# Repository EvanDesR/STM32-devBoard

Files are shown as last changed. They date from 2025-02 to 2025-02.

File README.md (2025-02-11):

# STM32-devBoard

At one point I was considering electrical or computer hardware engineering as a degree, but I decided to just keep it a hobby. This is most recent/best hardware project.

## Board design
Screenshot from 2025-02-10 18-38-12

## Connection plotter
Screenshot from 2025-02-10 18-38-58

## Did you know you can put corporate logos on PCBs, and JLCPCB wont complain?! 
Screenshot from 2025-02-10 18-39-17
Screenshot from 2025-02-10 18-52-23

## A closer look at the board layout. Designed with minimizing noise in mind.
Screenshot from 2025-02-10 18-52-32

## PCB render from development


## After finishing the .bom (bill of materials) file for JLCPCB, I submitted the design for approval, and manufactuering 



## About two weeks later...





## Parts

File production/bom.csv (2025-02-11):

Designator | Footprint | Quantity | Value | LCSC Part #
C1, C2 | 0805 | 2 | 22u | C45783
C10, C9 | 0402 | 2 | 1u | C52923
C11, C4, C5, C6, C7 | 0402 | 5 | 100n | C2981728
C12, C13 | 0402 | 2 | 8p | C342939
C3 | 0603 | 1 | 10u | C19702
C8 | 0402 | 1 | 10n | C15195
D1 | 0603 | 1 | RED | C2286
FB1 | 0805 | 1 | 120R | C160964
H1, H2 | MountingHole_2.2mm_M2 | 2 | MountingHole
J1, J3, J5 | PinHeader_1x04_P2.54mm_Vertical | 3 | Conn_01x04_Male | C2691448
J2 | MICRO-USB-SMD_5P-P0.65-H-F_U254-051T-4BH81-S2S | 1 | U254-051T-4BH81-S2S | C381144
J4 | PinHeader_1x04_P2.54mm_Vertical | 1 | Conn_01x04_Male | C2691448
R1, R3, R4, R5 | 0402 | 4 | 1k5 | C319978
R2 | 0402 | 1 | 10k | C269701
SW1 | SW_SPDT_PCM12 | 1 | SW_SPDT | C5149818
U1 | SOT-223-3_TabPin2 | 1 | AMS1117-3.3 | C6186
U2 | LQFP-48_7x7mm_P0.5mm | 1 | STM32F103C8T6 | C8734
Y1 | Crystal_SMD_3225-4Pin_3.2x2.5mm | 1 | 16MHz | C129740

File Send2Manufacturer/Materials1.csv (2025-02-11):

Source: | /home/wockyslush/kicads/ProjOne/ProjOne.kicad_sch
Date: | Tue 26 Mar 2024 10:59:46 PM
Tool: | Eeschema 6.0.2+dfsg-1
Generator: | /usr/share/kicad/plugins/bom_csv_grouped_by_value_with_fp.py
Component Count: | 31
Ref | Qnty | Value | Cmp name | Footprint | Description | Vendor
C1, C2, | 2 | 22u | C | Capacitor_SMD:C_0805_2012Metric | Unpolarized capacitor
C3, | 1 | 10u | C | Capacitor_SMD:C_0603_1608Metric_Pad1.08x0.95mm_HandSolder | Unpolarized capacitor
C4, C5, C6, C7, C11, | 5 | 100n | C | Capacitor_SMD:C_0402_1005Metric | Unpolarized capacitor
C8, | 1 | 10n | C | Capacitor_SMD:C_0402_1005Metric | Unpolarized capacitor
C9, C10, | 2 | 1u | C | Capacitor_SMD:C_0402_1005Metric | Unpolarized capacitor
C12, C13, | 2 | 10p | C | Capacitor_SMD:C_0402_1005Metric | Unpolarized capacitor
D1, | 1 | RED | LED | LED_SMD:LED_0603_1608Metric | Light emitting diode
FB1, | 1 | 120R | FerriteBead | Inductor_SMD:L_0201_0603Metric | Ferrite bead
J1, J3, J5, | 3 | Conn_01x04_Male | Conn_01x04_Male | Connector_PinHeader_2.54mm:PinHeader_1x04_P2.54mm_Vertical | Generic connector, single row, 01x04, script generated (kicad-library-utils/schlib/autogen/connector/)
J2, | 1 | USB_B_Micro | USB_B_Micro | Connector_USB:USB_Micro-B_Wuerth_629105150521 | USB Micro Type B connector
J4, | 1 | Conn_01x04_Male | Conn_01x04_Male | Connector_PinHeader_2.54mm:PinHeader_1x04_P2.54mm_Vertical | Generic connector, single row, 01x04, script generated (kicad-library-utils/schlib/autogen/connector/)
R1, R3, R4, R5, | 4 | 1k5 | R | Resistor_SMD:R_0402_1005Metric | Resistor
R2, | 1 | 10k | R | Resistor_SMD:R_0402_1005Metric | Resistor
SW1, | 1 | SW_SPDT | SW_SPDT | Button_Switch_THT:SW_E-Switch_EG1224_SPDT_Angled | Switch, single pole double throw
U1, | 1 | AMS1117-3.3 | AMS1117-3.3 | Package_TO_SOT_SMD:SOT-223-3_TabPin2 | 1A Low Dropout regulator, positive, 3.3V fixed output, SOT-223
U2, | 1 | STM32F103C8T6 | STM32F103C8Tx | Package_QFP:LQFP-48_7x7mm_P0.5mm | ARM Cortex-M3 MCU, 64KB flash, 20KB RAM, 72MHz, 2-3.6V, 37 GPIO, LQFP-48
Y1, | 1 | 16MHz | Crystal_GND24 | Crystal:Crystal_SMD_3225-4Pin_3.2x2.5mm | Four pin crystal, GND on pins 2 and 4

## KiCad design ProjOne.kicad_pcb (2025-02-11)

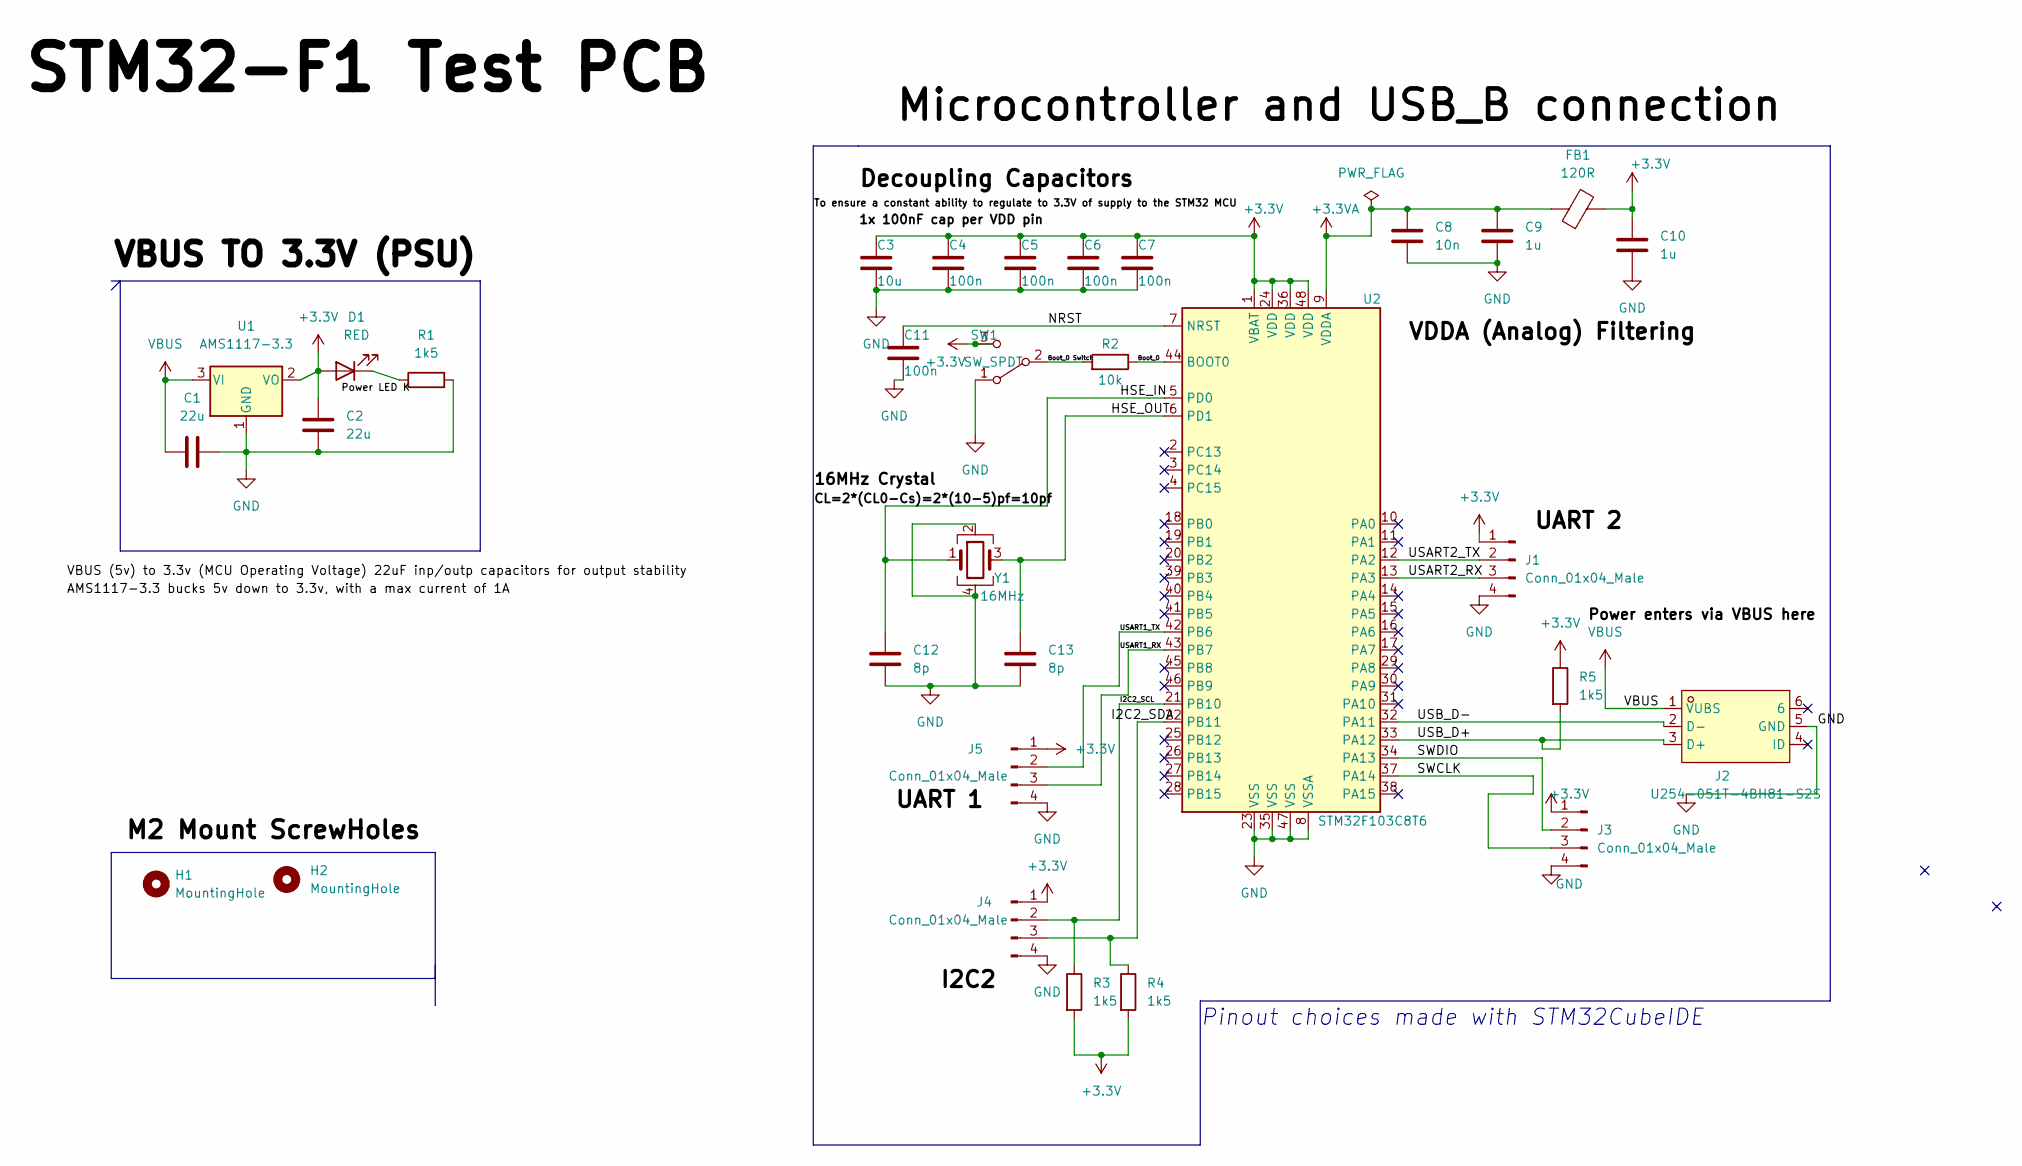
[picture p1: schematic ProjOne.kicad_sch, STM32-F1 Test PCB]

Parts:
C1, C2: 22u; C_0805_2012Metric; LCSC C45783
C3: 10u; C_0603_1608Metric_Pad1.08x0.95mm_HandSolder; LCSC C19702
C4, C5, C6, C7, C11: 100n; C_0402_1005Metric; LCSC C2981728
C8: 10n; C_0402_1005Metric; LCSC C15195
C9, C10: 1u; C_0402_1005Metric; LCSC C52923
C12, C13: 8p; C_0402_1005Metric; LCSC C342939
D1: RED; LED_0603_1608Metric; LCSC C2286
FB1: 120R; L_0805_2012Metric; LCSC C160964
H1, H2: MountingHole; MountingHole_2.2mm_M2
J1, J3, J4, J5: Conn_01x04_Male; PinHeader_1x04_P2.54mm_Vertical; LCSC C2691448
J2: U254-051T-4BH81-S2S; MICRO-USB-SMD_5P-P0.65-H-F_U254-051T-4BH81-S2S; LCSC Part C381144
R1, R3, R4, R5: 1k5; R_0402_1005Metric; LCSC C319978
R2: 10k; R_0402_1005Metric; LCSC C269701
SW1: SW_SPDT; SW_SPDT_PCM12; LCSC C5149818
U1: AMS1117-3.3; SOT-223-3_TabPin2; LCSC C6186
U2: STM32F103C8T6; LQFP-48_7x7mm_P0.5mm; LCSC C8734
Y1: 16MHz; Crystal_SMD_3225-4Pin_3.2x2.5mm; LCSC C129740

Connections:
+3.3VA: C8.1, C9.1, FB1.1, U2.9 (VDDA)
+3V3: C2.1, C3.1, C4.1, C5.1, C6.1, C7.1, C10.1, D1.2 (A), FB1.2, J1.1, J3.1, J4.1, J5.1, R3.2, R4.2, R5.1, SW1.3 (C), U1.2 (VO), U2.1 (VBAT), U2.24 (VDD), U2.36 (VDD), U2.48 (VDD)
/Boot_0: R2.1, U2.44 (BOOT0)
/Boot_0 Switch: R2.2, SW1.2 (B)
/HSE_IN: C12.1, U2.5 (PD0), Y1.1
/HSE_OUT: C13.1, U2.6 (PD1), Y1.3
/I2C2_SCL: J4.2, R3.1, U2.21 (PB10)
/NRST: C11.1, U2.7 (NRST)
/SWCLK: J3.3, U2.37 (PA14)
/SWDIO: J3.2, U2.34 (PA13)
/USART1_RX: J5.2, U2.42 (PB6)
/USART2_RX: J1.3, U2.13 (PA3)
/USART2_TX: J1.2, U2.12 (PA2)
/USB_D+: J2.3 (D+), R5.2, U2.33 (PA12)
/USB_D-: J2.2 (D-), U2.32 (PA11)
GND: C1.2, C2.2, C3.2, C4.2, C5.2, C6.2, C7.2, C8.2, C9.2, C10.2, C11.2, C12.2, C13.2, J1.4, J2.5 (GND), J3.4, J4.4, J5.4, R1.2, SW1.1 (A), U1.1 (GND), U2.8 (VSSA), U2.23 (VSS), U2.35 (VSS), U2.47 (VSS), Y1.2, Y1.4
unnamed: D1.1 (K), R1.1
unnamed: J4.3, R4.1, U2.22 (PB11)
unnamed: J5.3, U2.43 (PB7)
VBUS: C1.1, J2.1 (VUBS), U1.3 (VI)

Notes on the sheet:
Pinout choices made with STM32CubeIDE

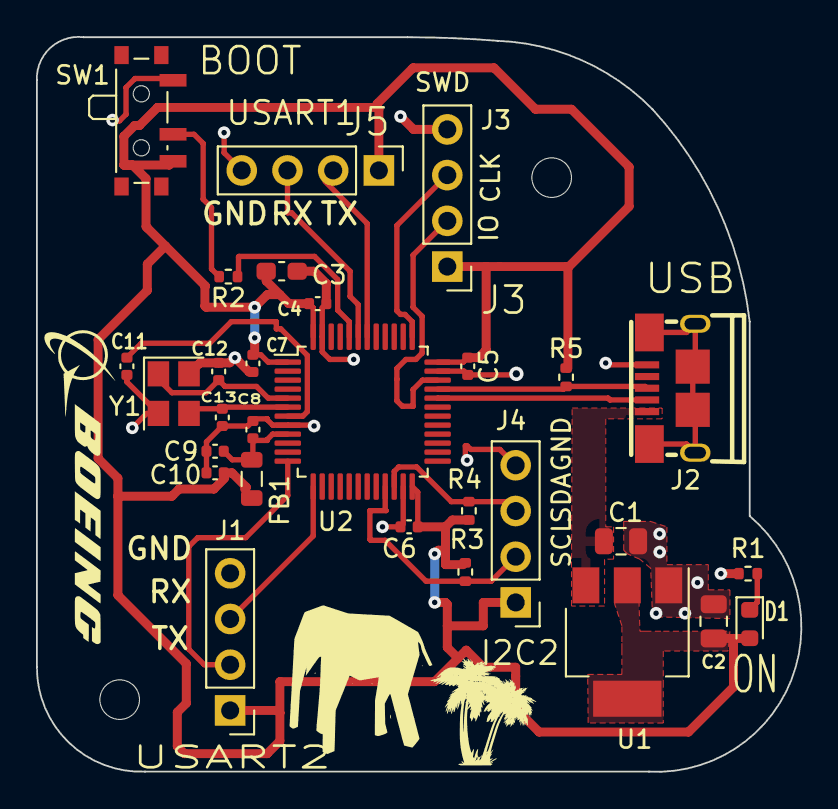
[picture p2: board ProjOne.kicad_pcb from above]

Board: 2 copper layers, 42.5 x 40.8 mm, 31 parts (0 on the bottom side), 20 nets.
